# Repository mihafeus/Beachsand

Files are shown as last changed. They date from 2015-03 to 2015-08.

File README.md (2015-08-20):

# Beachsand
Project Beachsand is all about low-power easy to set-up RF sensor networks. At the moment it consists of SenseGrain and  SandCasle, with ActGrain coming some time in the future. 

The SenseGrain is an Attiny85 with an RF transmitter and a battery. The SandCastle is an Arduino with an RF receiver. Once assembled the only thing the user needs to do is select the update frequency. At the moment those are continuous, 5 sec, 30 sec, 5 min, 30 min, 2h, 6h, 24h and on interrupt. The update frequency has a great affect on the battery life - on continuous mode the battery should last a good month, on all the time modes 3-4 years and on interrupt up to 30 years (theoretically). After the initial setup all the user has to do is add the analog sensor or switch to the SenseGrain. The last step is to leave the SenseGrain in the location where it needs to measure things and then forget about it for a very long time.

The SenseGrain then keeps transmitting it’s name and the value from the analog sensor according to the intervals it was set up to. Those values are then received by the SandCastle and can from there be used for whatever application they are needed. One SandCastle can receive values from multiple SenseGrains.

TO DO:
- ActGrain remote wakeup and auto-pair
- Improve documentation
- Visualize the set-up process
- Create direct connections between SenseGrain and ActGrain
- Create SandCastle Arduino shield with Wi-fi and SD-card support, for logging and sending values without the need of a PC

Wishlist:
- Web dashboard
- Solar power
- Mesh network

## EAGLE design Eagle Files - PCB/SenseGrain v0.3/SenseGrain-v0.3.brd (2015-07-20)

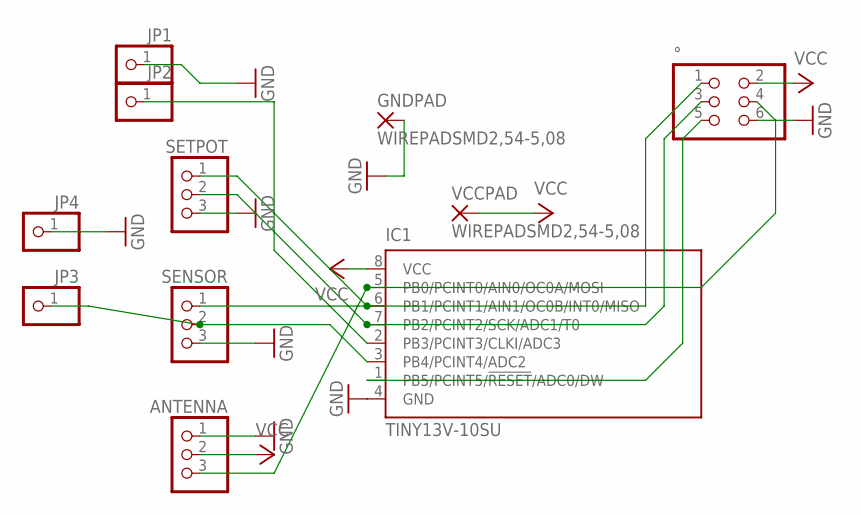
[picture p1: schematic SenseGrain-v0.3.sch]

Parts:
ANTENNA: PINHD-1X3CB; 1X03-CLEANBIG
GNDPAD: WIREPADSMD2,54-5,08; SMD2,54-5,08
IC1: TINY13V-10SU; 8S2
JP1, JP2, JP3, JP4: PINHD-1X1; 1X01
SENSOR: PINHD-1X3CB; 1X03-CLEANBIG
SETPOT: PINHD-1X3CB; 1X03-CLEANBIG
VCCPAD: WIREPADSMD2,54-5,08; SMD2,54-5,08
°: PINHD-2X3; 2X03

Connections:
GND: ANTENNA.1, GNDPAD.1, IC1.4 (GND), JP1.1, JP4.1, SENSOR.3, SETPOT.3, °.6
unnamed: IC1.6 (PB1/PCINT1/AIN1/OC0B/INT0/MISO), SENSOR.1, SETPOT.1, °.1
unnamed: ANTENNA.3, IC1.5 (PB0/PCINT0/AIN0/OC0A/MOSI), °.4
unnamed: IC1.3 (PB4/PCINT4/ADC2), JP3.1, SENSOR.2
unnamed: IC1.2 (PB3/PCINT3/CLKI/ADC3), JP2.1
unnamed: IC1.1 (PB5/PCINT5/!RESET!/ADC0/DW), °.5
unnamed: IC1.7 (PB2/PCINT2/SCK/ADC1/T0), SETPOT.2, °.3
VCC: ANTENNA.2, IC1.8 (VCC), VCCPAD.1, °.2

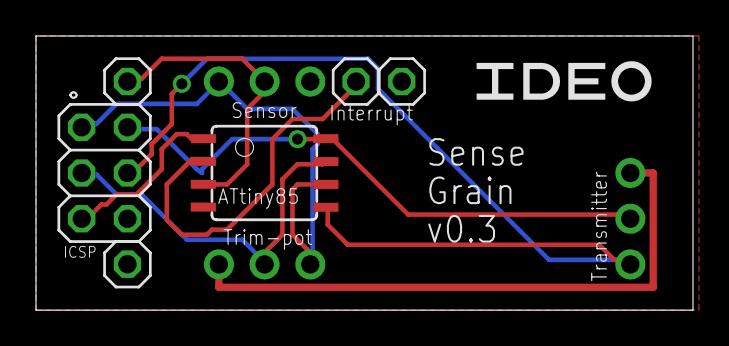
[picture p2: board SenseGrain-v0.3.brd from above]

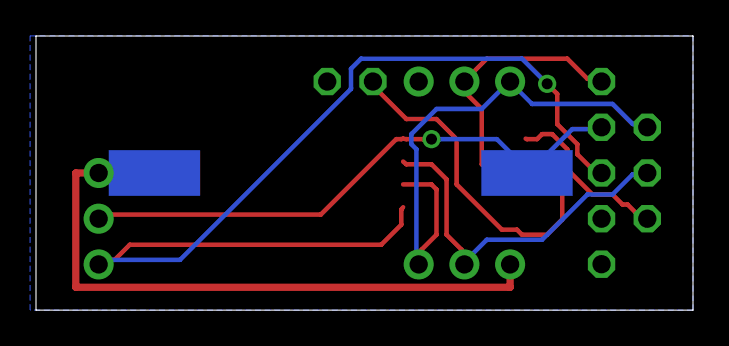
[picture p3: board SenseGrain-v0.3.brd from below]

Board: 2 copper layers, 36.5 x 15.2 mm, 11 parts (2 on the bottom side), 8 nets.

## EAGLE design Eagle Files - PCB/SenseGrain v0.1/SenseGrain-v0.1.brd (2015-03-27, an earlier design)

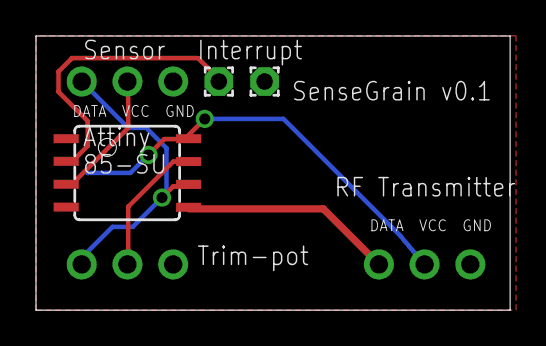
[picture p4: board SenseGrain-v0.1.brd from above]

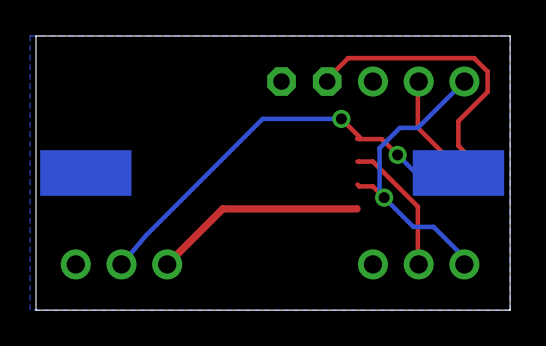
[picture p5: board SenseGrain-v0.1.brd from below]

Board: 2 copper layers, 26.3 x 15.2 mm, 8 parts (2 on the bottom side), 7 nets.

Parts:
ANTENNA: 1X03-CLEANBIG
GNDPAD: WIREPADSMD2,54-5,08; SMD2,54-5,08
IC1: TINY13V-10SU; 8S2
PAD3, PAD4: 1,6/0,9
SENSOR: 1X03-CLEANBIG
SETPOT: 1X03-CLEANBIG
VCCPAD: WIREPADSMD2,54-5,08; SMD2,54-5,08

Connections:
GND: ANTENNA.1, GNDPAD.1, IC1.4, PAD4.1, SENSOR.3, SETPOT.3
unnamed: IC1.6, SENSOR.1, SETPOT.1
unnamed: ANTENNA.3, IC1.5
unnamed: IC1.3, SENSOR.2
unnamed: IC1.7, SETPOT.2
unnamed: IC1.2, PAD3.1
VCC: ANTENNA.2, IC1.8, VCCPAD.1

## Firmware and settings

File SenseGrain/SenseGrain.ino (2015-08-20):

#include <avr/sleep.h>
#include <avr/wdt.h>
#include <avr/interrupt.h>
#include <VirtualWire.h>
#include <EEPROM.h>

volatile boolean f_wdt = 1;

//Variables
const int switchPin = 3;            // Interrupt pin
const int powerPin = 1;             // Power saving for the sensor
int Sensor1Data;
int Sensor1DataOld;
char Sensor1CharMsg[4]; 
 
int timer = 0;                      // Sets the number of wake up times after which to send data
int counter = 0;                    // Counts the times the microcontroller has woken up
int masterSwitch;                   // This switch on either interrupt sleep or timer sleep
int wdSetup;                        // Watchdog setup number // 0=16ms, 1=32ms,2=64ms,3=128ms,4=250ms,5=500ms 6=1 sec,7=2 sec, 8=4 sec, 9= 8sec

String SendStr;
String NameStr = "";                // The name of the transmitter has to consist of 5 characters // If no name is specified, read the given name from the EEPROM

String timerStr = "Not set";

char letter;
byte value;

boolean treshold = false;

void setup() {                      // Set Up Instrictions


  pinMode(powerPin, OUTPUT);
  digitalWrite(powerPin, HIGH);     // Sensor power on

  timerSetup();                     // Runs the function to set up the timer 

  digitalWrite(powerPin, LOW);      // Power saving mode enabled

  if(NameStr == ""){                // If no name is specified, read the given name from the EEPROM
    for (int i = 0; i < 5; i++){
      value = EEPROM.read(i);
      letter = value;
      NameStr += String(letter); 
    }
  }

  pinMode(switchPin, INPUT);
  digitalWrite(switchPin, HIGH);

  // Transmitter code
  //vw_set_ptt_inverted(true);       // Note to self: I might need to re-enable this
  vw_set_tx_pin(0);                  // Transmitter pin
  vw_setup(1000);                    // Speed of data transfer Kbps

  transmitFunc(NameStr);
  transmitFunc(timerStr);

}


void loop() {

  if(masterSwitch==0){               // Timer sleep mode

    if (f_wdt==1) {                  // Wait for timed out watchdog / flag is set when a watchdog timeout occurs
      f_wdt=0;                       // Reset flag

      if(counter>=timer){            // If the counter has not reached the desired timer value, it goes back to sleep
        counter=0;                   // If counter has reached the timer value, it resets the counter and
        SensorRead();                // Tiggers reading the sensor values
      }
      counter++;
      system_sleep();
    }
  }

  if(masterSwitch==1){                // Interrupt sleep mode
    SensorRead();
    sleep(); 
  }
}

void SensorRead(){

  digitalWrite(powerPin, HIGH);       // Provides power to the sensor
  Sensor1Data = analogRead(A2);       // Reading the sensor

  if(timerStr=="Treshold"){  

    if (analogRead(A2)<analogRead(A1) && treshold==false) {
      treshold=true;
      SendStr=NameStr+Sensor1Data;    // Combinig name with sensor values
      transmitFunc(SendStr);
    }
    else if(analogRead(A2)>analogRead(A1) && treshold==true){
      treshold=false;
      SendStr=NameStr+Sensor1Data;    // Combinig name with sensor values
      transmitFunc(SendStr);
    }
  }
  else{
    SendStr=NameStr+Sensor1Data;      // Combinig name with sensor values
    transmitFunc(SendStr);
  }
  digitalWrite(powerPin, LOW);        // Cuts power from the sensor
}

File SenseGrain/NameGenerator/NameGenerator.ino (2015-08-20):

#include <EEPROM.h>
char Char;
String letter;
String name = "";
boolean conso = false;
boolean vowel = false;
int shiftkey = 64;
boolean nameWritten = false;
byte value;

void setup() {
  randomSeed((analogRead(A2)*analogRead(A1)*analogRead(A3))/3);
}

void loop() {
  whatsmyname();
}

void whatsmyname(){
  
  randomSeed((analogRead(A2)*analogRead(A1)*analogRead(A3))/3);
  
  if(name==""){
    shiftkey = 65;
  }
  else{
    shiftkey = 97;
  }

  Char = random(26)+shiftkey;

  letter = String(Char);

  if(letter == "A" || letter == "E" || letter =="I" || letter =="O" || 
    letter =="U" || letter == "a" || letter == "e" || letter =="i" || 
    letter =="o" || letter =="u"){

    if(vowel == false){
      name += letter;
      vowel = true;
      conso = false;
    }
  }
  else{

    if(conso == false){
      name += letter;
      vowel = false;
      conso = true;
    }
  }

  if(name.length()==4){

    name += String(random(1,10));
    vowel = false;
    conso = false;

    if(nameWritten == false){
      for (int i = 0; i < name.length(); i++){
        EEPROM.write(i, name[i]);
        nameWritten = true;
      }
    } 
  }
}

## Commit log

2015-03-27 put files into own folder
    [SenseGrain v0.1.brd, SenseGrain v0.1.sch]
2015-07-10 SenseGrain PCB v0.2
    Added Eagle files for SenseGrain v0.2 PCB together with Gerber files
    [SenseGrain v0.1.brd, SenseGrain v0.1.sch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]
2015-07-15 Added Fritzing files
    - Added Fritzing files
    - Updated TO-DO
    - renamed folders
    [SandCastle.fzz, SenseGrain.fzz]
2015-07-16 Improved SandCastle code
    Now you can plug in the receiver directly to the Arduino. Just don’t
    forget to cut the CS pin on the receiver
    [SandCastle.fzz]
2015-07-20 New version of the PCB
    [SenseGrain-v0.1.brd, SenseGrain-v0.1.sch, SenseGrain-v0.3.brd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]
2015-07-20 Updated SandCastle code
    Now you can plug the receiver straight into the Arduino
    [SandCastle.fzz]
2015-08-17 Added missing Virtual Wire library and ATtiny hardware folder
    ATtiny folder was taken from here
    https://code.google.com/p/arduino-tiny/downloads/list
2015-08-20 Updated name generator
    Upload the name generator before you upload the SenseGrain code. That
    is, if you are tired of coming up with names.
